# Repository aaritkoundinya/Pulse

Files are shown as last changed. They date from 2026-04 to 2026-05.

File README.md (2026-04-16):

# Pulse

Single-repo KiCad workspace for all Pulse board revisions.

## Repository Structure

- `boards/r2/` - imported from your existing `pulser2`
- `boards/r2.1/` - imported from your existing `pulser2.1`
- `templates/scratch-board/` - starter template for clean-slate revisions
- `tools/new_revision.sh` - helper script to create new revisions

Each board folder has its own KiCad-focused `.gitignore`.

## Create New Revisions

Build from an existing revision:

```bash
./tools/new_revision.sh r3 --from r2.1
```

Start from scratch:

```bash
./tools/new_revision.sh r3 --scratch
```

After creation, open KiCad and work in `boards/<revision>/`.

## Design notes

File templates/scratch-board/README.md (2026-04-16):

# Scratch KiCad Revision Template

Use this template when starting a brand-new board revision from zero.

Recommended first files to create in your new revision folder:
- `<revision>.kicad_pro`
- `<revision>.kicad_sch`
- `<revision>.kicad_pcb`

This folder already includes a KiCad-focused `.gitignore`.

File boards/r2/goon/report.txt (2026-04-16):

Info: Output directory 'C:\Users\roopa\Desktop\Basic Computer\airbrakes\goon' created.
Plotted to 'C:\Users\roopa\Desktop\Basic Computer\airbrakes\goon\airbrakes-F_Cu.gbr'.
Plotted to 'C:\Users\roopa\Desktop\Basic Computer\airbrakes\goon\airbrakes-B_Cu.gbr'.
Plotted to 'C:\Users\roopa\Desktop\Basic Computer\airbrakes\goon\airbrakes-F_Paste.gbr'.
Plotted to 'C:\Users\roopa\Desktop\Basic Computer\airbrakes\goon\airbrakes-B_Paste.gbr'.
Plotted to 'C:\Users\roopa\Desktop\Basic Computer\airbrakes\goon\airbrakes-F_Silkscreen.gbr'.
Plotted to 'C:\Users\roopa\Desktop\Basic Computer\airbrakes\goon\airbrakes-B_Silkscreen.gbr'.
Plotted to 'C:\Users\roopa\Desktop\Basic Computer\airbrakes\goon\airbrakes-F_Mask.gbr'.
Plotted to 'C:\Users\roopa\Desktop\Basic Computer\airbrakes\goon\airbrakes-B_Mask.gbr'.
Plotted to 'C:\Users\roopa\Desktop\Basic Computer\airbrakes\goon\airbrakes-Edge_Cuts.gbr'.
Created Gerber job file 'C:\Users\roopa\Desktop\Basic Computer\airbrakes\goon\airbrakes-job.gbrjob'.
Info: Done.
Plotted to 'C:\Users\roopa\Desktop\Basic Computer\airbrakes\goon\airbrakes-F_Cu.gbr'.
Plotted to 'C:\Users\roopa\Desktop\Basic Computer\airbrakes\goon\airbrakes-B_Cu.gbr'.
Plotted to 'C:\Users\roopa\Desktop\Basic Computer\airbrakes\goon\airbrakes-F_Paste.gbr'.
Plotted to 'C:\Users\roopa\Desktop\Basic Computer\airbrakes\goon\airbrakes-B_Paste.gbr'.
Plotted to 'C:\Users\roopa\Desktop\Basic Computer\airbrakes\goon\airbrakes-F_Silkscreen.gbr'.
Plotted to 'C:\Users\roopa\Desktop\Basic Computer\airbrakes\goon\airbrakes-B_Silkscreen.gbr'.
Plotted to 'C:\Users\roopa\Desktop\Basic Computer\airbrakes\goon\airbrakes-F_Mask.gbr'.
Plotted to 'C:\Users\roopa\Desktop\Basic Computer\airbrakes\goon\airbrakes-B_Mask.gbr'.
Plotted to 'C:\Users\roopa\Desktop\Basic Computer\airbrakes\goon\airbrakes-Edge_Cuts.gbr'.
Created Gerber job file 'C:\Users\roopa\Desktop\Basic Computer\airbrakes\goon\airbrakes-job.gbrjob'.
Info: Done.
Info: Done.
Info: Done.

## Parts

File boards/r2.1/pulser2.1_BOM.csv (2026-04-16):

Id | Designator | Footprint | Quantity | Designation | Supplier and ref
1 | U2 | SOT-23-5 | 1 | SPX3819M5-L-1-8
2 | C28 | C_0603_1608Metric | 1 | 10nF
3 | C25 | C_Elec_3x5.4 | 1 | 2.2uF
4 | R3,R4 | R_0603_1608Metric | 2 | 1k
5 | C16,C15 | C_0603_1608Metric | 2 | 15pF
6 | R6,R8,R9,R7 | R_0603_1608Metric | 4 | 4.7K
7 | U1 | QFN-56-1EP_7x7mm_P0.4mm_EP3.2x3.2mm | 1 | RP2040
8 | C22,C21,C23 | C_0603_1608Metric | 3 | 0.1uF
9 | PWR1,SW1 | PinHeader_1x02_P2.54mm_Vertical | 2 | Conn_01x02_Pin
10 | C20,C19 | C_0603_1608Metric | 2 | 100nf
11 | C26,C27 | C_0603_1608Metric | 2 | 22uF
12 | C17,C13,C14 | C_0603_1608Metric | 3 | 10uF
13 | BZ1 | MagneticBuzzer_CUI_CMT-8504-100-SMT | 1 | Buzzer
14 | U3 | SOT23-5 | 1 | AP2112K-3.3
15 | C24,C1,C4 | C_0603_1608Metric | 3 | 1uF
16 | R5,R11 | R_0603_1608Metric | 2 | 10K
17 | USB1 | USB_Micro-B_Wuerth_629105150521 | 1 | USB_B_Micro
18 | IMU1 | InvenSense_QFN-24_3x3mm_P0.4mm | 1 | ICM-20948
19 | CLOCK1 | XTAL_ABM8-272-T3 | 1 | ABM8-272-T3
20 | C18,C12,C9,C7,C10,C6,C8,C3,C11,C2,C5 | C_0603_1608Metric | 11 | 100nF
21 | D2,D5 | D_0603_1608Metric | 2 | D_Schottky
22 | L1 | L_0603_1608Metric | 1 | 2.2uH
23 | G1 | LED_0603_1608Metric | 1 | GREEN
24 | BMP1 | BMP581 | 1 | BMP581
25 | R12 | LED_0603_1608Metric | 1 | RED
26 | SERVO1 | PinHeader_1x03_P2.54mm_Horizontal | 1 | Conn_01x03_Pin
27 | U6 | SOT-563 | 1 | AP62250Z6
28 | BOOTSL1,RST1 | Push_SMD_4.2x3.2mm | 2 | SMD_4.2x3.2mm_h2.5mm
29 | R1,R2 | R_0603_1608Metric | 2 | 27.4
30 | FLASH1 | SOIC-8_5.3x5.3mm_P1.27mm | 1 | W25Q128JVS
31 | RADIO1,GPIO1 | JST_PH_B4B-PH-K_1x04_P2.00mm_Vertical | 2 | Conn_01x04_Socket
32 | R10 | R_0603_1608Metric | 1 | 52.3K
33 | D1 | LED_0603_1608Metric | 1 | LED

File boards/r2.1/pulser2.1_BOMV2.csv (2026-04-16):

Id | Designator | Footprint | Quantity | Designation | Supplier and ref
1 | R3,R4 | R_0603_1608Metric | 2 | 1k
2 | C21,C18,C12,C23,C9,C7,C10,C6,C8,C3,C11,C2,C5 | C_0603_1608Metric | 13 | 100nF
3 | C16,C15 | C_0603_1608Metric | 2 | 15pF
4 | U1 | QFN-56-1EP_7x7mm_P0.4mm_EP3.2x3.2mm | 1 | RP2040
5 | PWR,SW1 | PinHeader_1x02_P2.54mm_Vertical | 2 | Conn_01x02_Pin
6 | C20,C19 | C_0603_1608Metric | 2 | 100nf
7 | C26,C27 | C_0603_1608Metric | 2 | 22uF
8 | C17,C13,C14 | C_0603_1608Metric | 3 | 10uF
9 | BZ | Buzzer_CUI_CPT-9019S-SMT | 1 | Buzzer
10 | U3 | SOT23-5 | 1 | AP2112K-3.3
11 | U5 | ST_LGA-14L_2.5x3.0mm_P0.5mm_4x3 | 1 | LSM6DSOX
12 | R5,R11 | R_0603_1608Metric | 2 | 10K
13 | USB | USB_Micro-B_Wuerth_629105150521 | 1 | USB_B_Micro
14 | CLOCK1 | XTAL_ABM8-272-T3 | 1 | ABM8-272-T3
15 | C1,C4 | C_0603_1608Metric | 2 | 1uF
16 | D2,D5 | D_SOD-323_HandSoldering | 2 | D_Schottky
17 | L1 | L_0603_1608Metric | 1 | 2.2uH
18 | G1 | LED_0603_1608Metric | 1 | GREEN
19 | BMP | BMP581 | 1 | BMP581
20 | R13,R14 | R_0402_1005Metric | 2 | 680
21 | R12 | LED_0603_1608Metric | 1 | RED
22 | SERVO | PinHeader_1x03_P2.54mm_Horizontal | 1 | Conn_01x03_Pin
23 | R6,R7 | R_0603_1608Metric | 2 | 4.7K
24 | U6 | SOT-563 | 1 | AP62250Z6
25 | BOOTSL,RST | Push_SMD_4.2x3.2mm | 2 | SMD_4.2x3.2mm_h2.5mm
26 | R1,R2 | R_0603_1608Metric | 2 | 27.4
27 | FLASH | WSON-8-1EP_6x5mm_P1.27mm_EP3.4x4.3mm | 1 | W25Q128JVS
28 | RADIO1,GPIO | JST_PH_B4B-PH-K_1x04_P2.00mm_Vertical | 2 | Conn_01x04_Socket
29 | R10 | R_0603_1608Metric | 1 | 52.3K
30 | D1 | LED_0603_1608Metric | 1 | LED
31 | R15 | R_0402_1005Metric | 1 | 1k

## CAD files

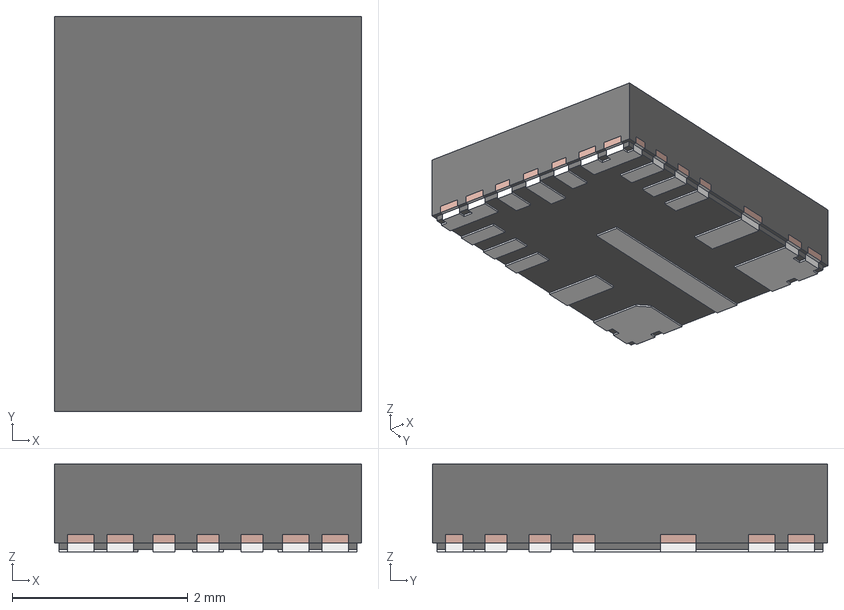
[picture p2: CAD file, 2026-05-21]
boards/r3/LM62460Q5RPHRQ1/RPH0016A.stp
3.50 x 4.50 x 1.00 mm
FRAME_AF0
BODY_AF0
PIN1_AREA

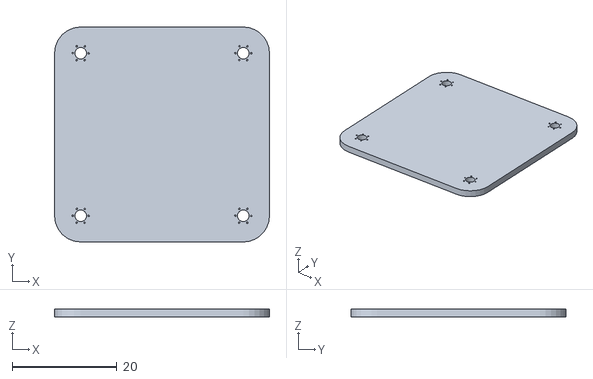
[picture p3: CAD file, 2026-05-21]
boards/r3/pulser3.stl
41.0 x 41.0 x 1.51

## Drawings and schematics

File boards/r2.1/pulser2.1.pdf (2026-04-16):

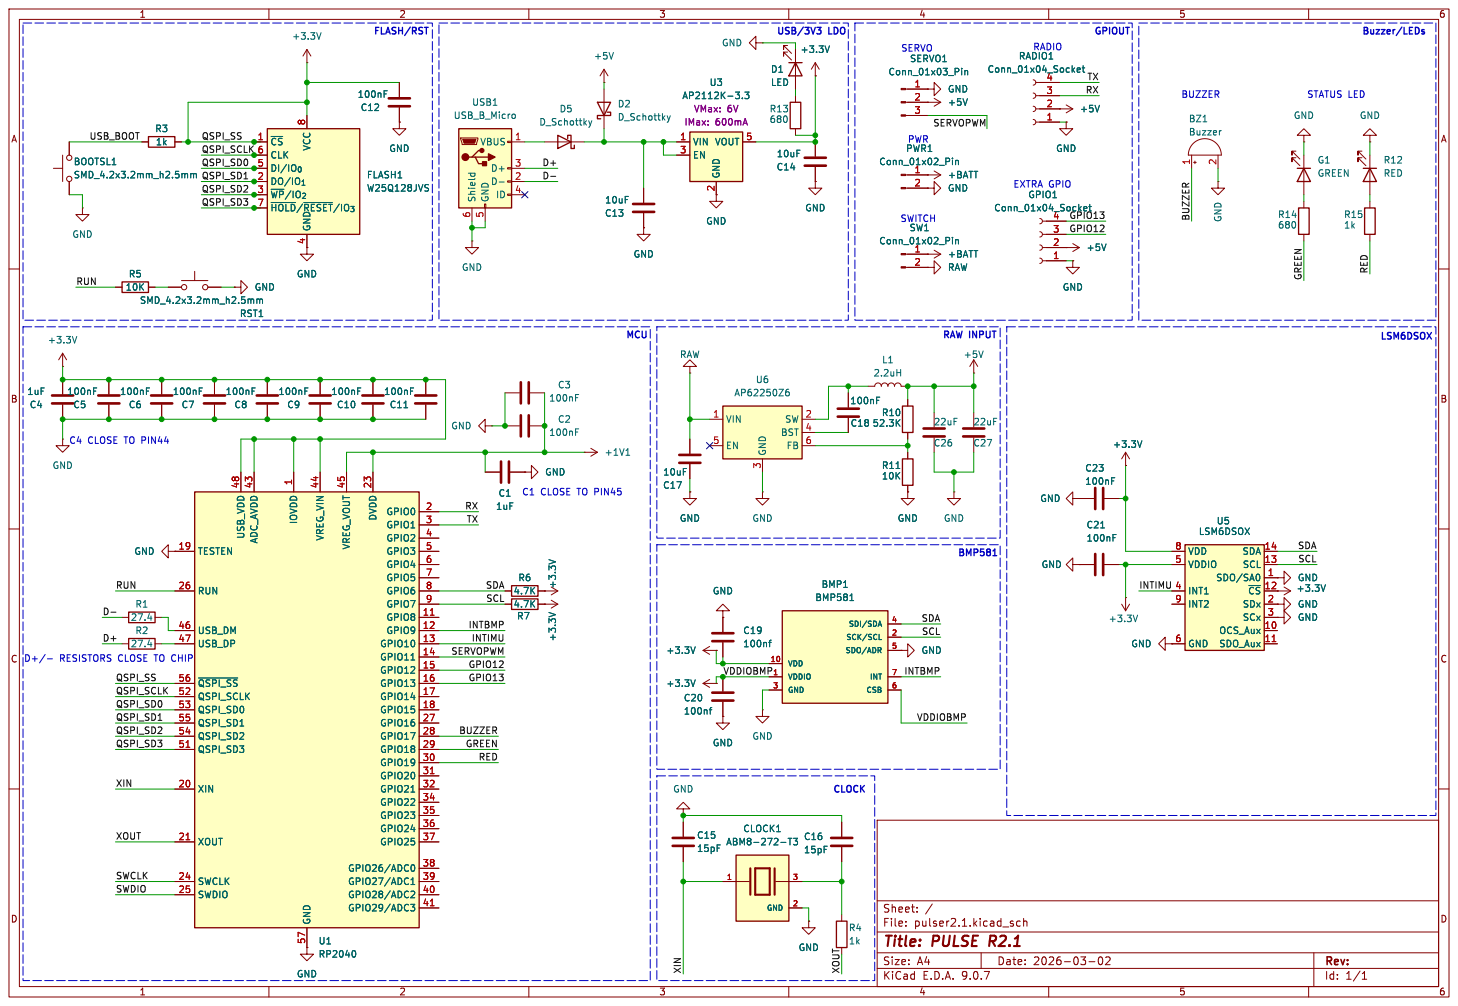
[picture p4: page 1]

File: pulser2.1.kicad_sch Sheet: / GND GND

3 SW 2 BST 4 FB 6 U6 AP62250Z6 GND

LSM6DSOX
SDA 14 SCL 13 ~{CS} 12 OCS_Aux 10 SDO_Aux 11 VDD 8 VDDIO 5

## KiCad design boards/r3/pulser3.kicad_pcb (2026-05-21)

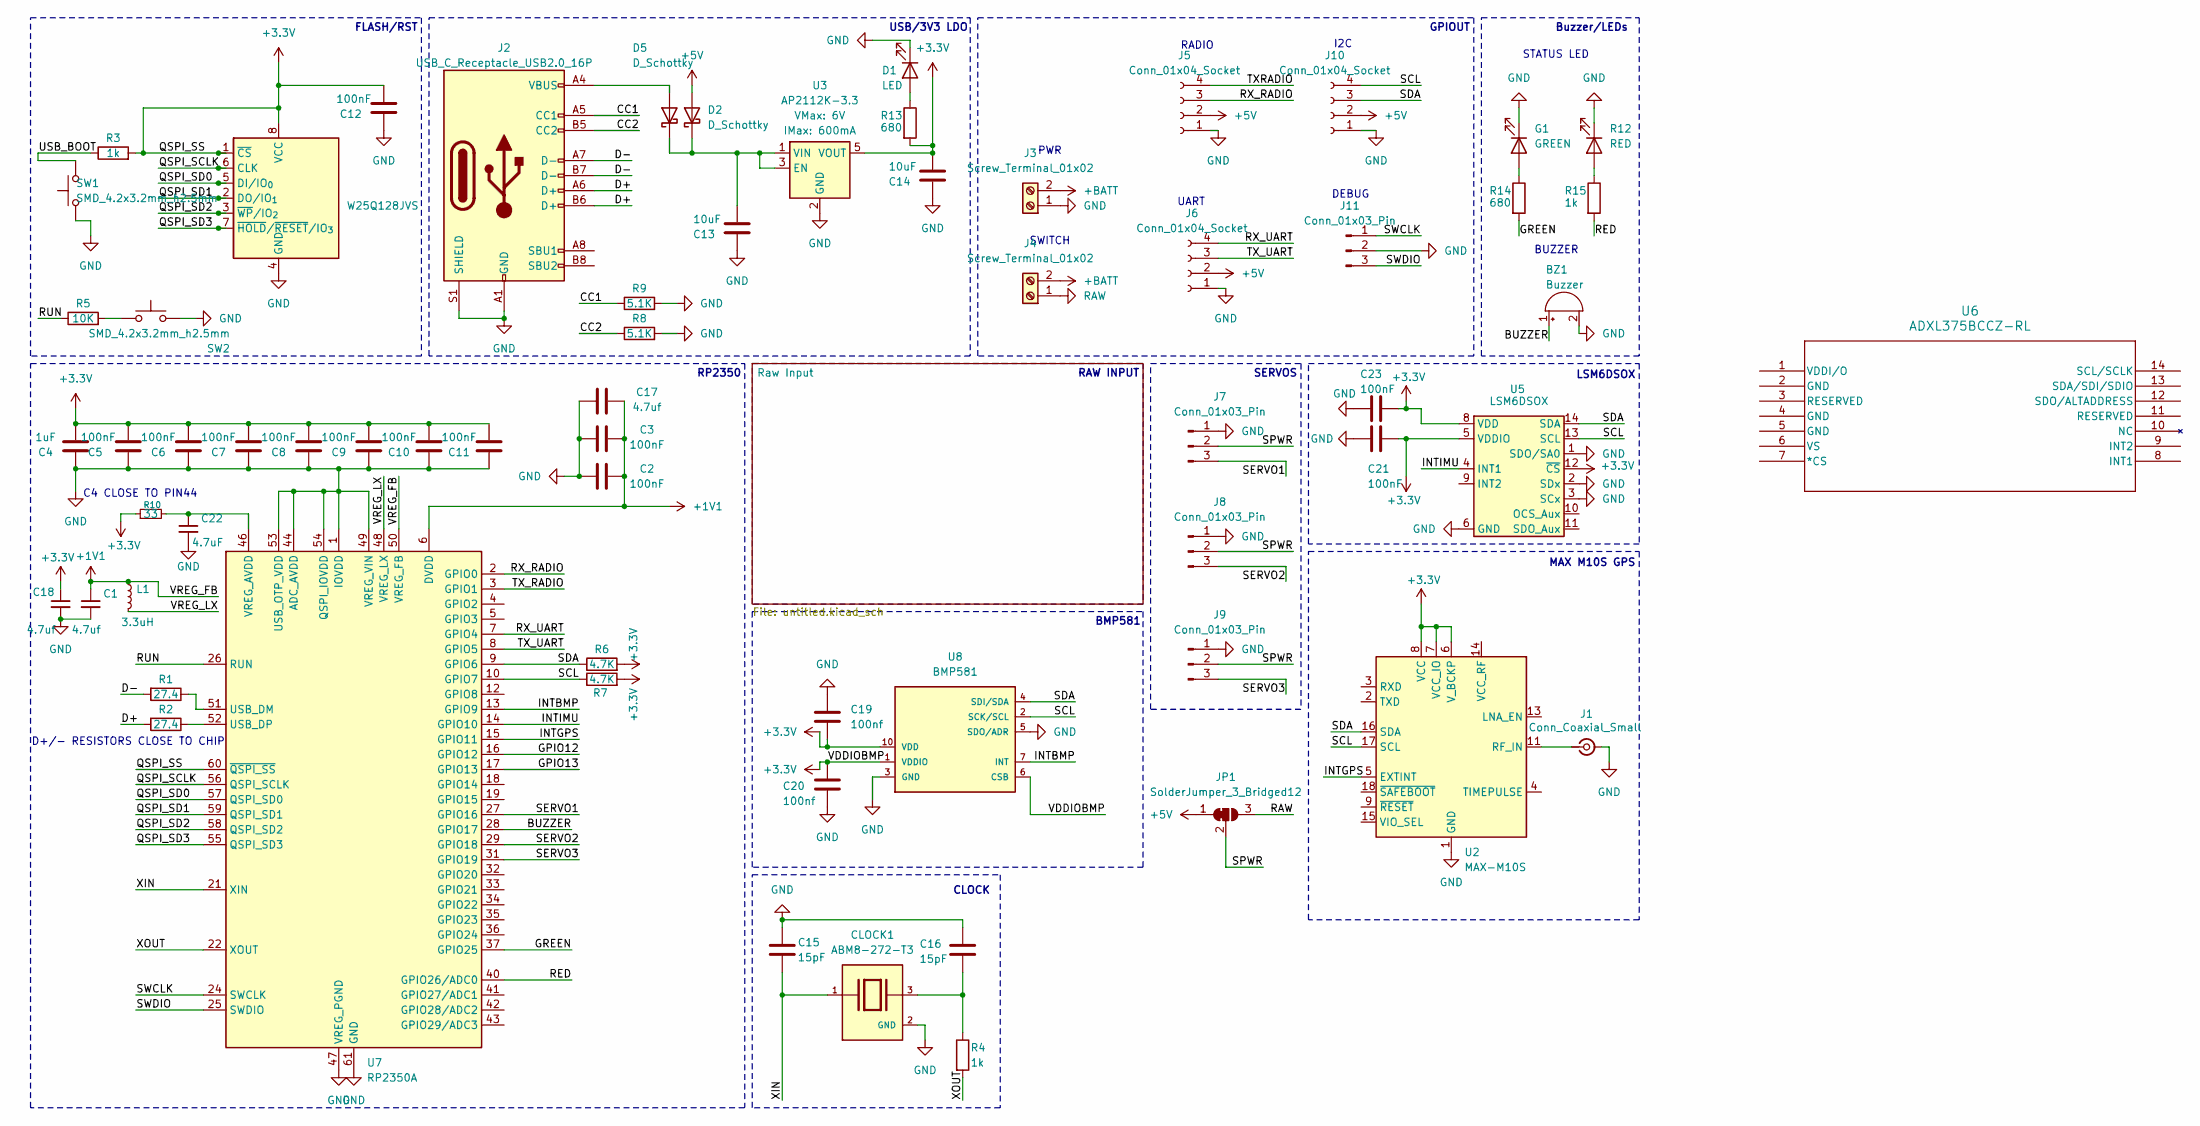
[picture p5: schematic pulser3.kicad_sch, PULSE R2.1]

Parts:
BZ1: Buzzer; Buzzer_CUI_CPT-9019S-SMT
C1, C17, C18: 4.7uf; C_0402_1005Metric
C2, C3, C5, C6, C7, C8, C9, C10, C11, C12, C21, C23: 100nF; C_0402_1005Metric
C4: 1uF; C_0402_1005Metric
C13, C14: 10uF; C_0805_2012Metric
C15, C16: 15pF; C_0402_1005Metric
C19, C20: 100nf; C_0402_1005Metric
C22: 4.7uF; C_0402_1005Metric
CLOCK1: ABM8-272-T3; XTAL_ABM8-272-T3; PARTREV 07-29-20
D1: LED; LED_0603_1608Metric
D2, D5: D_Schottky; D_SOD-323_HandSoldering
G1: GREEN; LED_0603_1608Metric
J1: Conn_Coaxial_Small; U.FL_Molex_MCRF_73412-0110_Vertical
J2: USB_C_Receptacle_USB2.0_16P; USB_C_Receptacle_JAE_DX07S016JA1R1500
J3, J4: Screw_Terminal_01x02; TerminalBlock_Phoenix_MPT-0,5-2-2.54_1x02_P2.54mm_Horizontal
J5, J6, J10: Conn_01x04_Socket; JST_SH_BM04B-SRSS-TB_1x04-1MP_P1.00mm_Vertical
J7, J8, J9, J11: Conn_01x03_Pin; JST_SH_BM03B-SRSS-TB_1x03-1MP_P1.00mm_Vertical
JP1: SolderJumper_3_Bridged12; SolderJumper-3_P1.3mm_Open_RoundedPad1.0x1.5mm
L1: 3.3uH; Untitled
R1, R2: 27.4; R_0402_1005Metric
R3, R4, R15: 1k; R_0402_1005Metric
R5: 10K; R_0402_1005Metric
R6, R7: 4.7K; R_0402_1005Metric
R8, R9: 5.1K; R_0402_1005Metric
R10: 33; R_0402_1005Metric
R12: RED; LED_0603_1608Metric
R13, R14: 680; R_0402_1005Metric
SW1, SW2: SMD_4.2x3.2mm_h2.5mm; Push_SMD_4.2x3.2mm
U1: W25Q128JVS; WSON-8-1EP_6x5mm_P1.27mm_EP3.4x4.3mm
U2: MAX-M10S; ublox_MAX
U3: AP2112K-3.3; SOT23-5
U5: LSM6DSOX; ST_LGA-14L_2.5x3.0mm_P0.5mm_4x3
U6: ADXL375BCCZ-RL
U7: RP2350A; QFN-60-1EP_7x7mm_P0.4mm_EP3.4x3.4mm
U8: BMP581

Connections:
+1V1: C1.1, C2.2, C3.2, C17.2, L1.1, U7.6 (DVDD), U7.23 (DVDD), U7.39 (DVDD), U7.50 (VREG_FB)
+3.3V: C4.1, C5.1, C6.1, C7.1, C8.1, C9.1, C10.1, C11.1, C12.1, C14.1, C18.1, C19.2, C20.1, C21.2, C23.2, R3.2, R6.2, R7.2, R10.1, R13.2, U1.1 (~CS), U1.8 (VCC), U2.6 (V_BCKP), U2.7 (VCC_IO), U2.8 (VCC), U3.5 (VOUT), U5.5 (VDDIO), U5.8 (VDD), U5.12 (~CS), U7.60 (~QSPI_SS), U8.1 (VDDIO), U8.6 (CSB), U8.10 (VDD)
+5V: D2.2 (A), J5.2, J6.2, J10.2, JP1.1 (A)
+BATT: J3.2, J4.2
/BUZZER: BZ1.1 (+), U7.28 (GPIO17)
/CC1: J2.A5 (CC1), R9.1
/CC2: J2.B5 (CC2), R8.1
/D+: J2.A6 (D+), J2.B6 (D+), R2.2
/D-: J2.A7 (D-), J2.B7 (D-), R1.2
/GPIO12: U7.16 (GPIO12)
/GPIO13: U7.17 (GPIO13)
/GREEN: R14.2, U7.37 (GPIO25)
/INTBMP: U7.13 (GPIO9), U8.7 (INT)
/INTGPS: U2.5 (EXTINT), U7.15 (GPIO11)
/INTIMU: U5.4 (INT1), U7.14 (GPIO10)
/QSPI_SCLK: U1.6 (CLK), U7.56 (QSPI_SCLK)
/QSPI_SD0: U1.5 (DI/IO_{0}), U7.57 (QSPI_SD0)
/QSPI_SD1: U1.2 (DO/IO_{1}), U7.59 (QSPI_SD1)
/QSPI_SD2: U1.3 (~WP/IO_{2}), U7.58 (QSPI_SD2)
/QSPI_SD3: U1.7 (~HOLD/~RESET/IO_{3}), U7.55 (QSPI_SD3)
/RED: R15.2, U7.40 (GPIO26/ADC0)
/RUN: R5.1, U7.26 (RUN)
/RX_RADIO: J5.3, U7.2 (GPIO0)
/RX_UART: J6.4, U7.7 (GPIO4)
/SCL: J10.4, R7.1, U2.17 (SCL), U5.13 (SCL), U7.10 (GPIO7), U8.2 (SCK/SCL)
/SDA: J10.3, R6.1, U2.16 (SDA), U5.14 (SDA), U7.9 (GPIO6), U8.4 (SDI/SDA)
/SERVO1: J7.3, U7.27 (GPIO16)
/SERVO2: J8.3, U7.29 (GPIO18)
/SERVO3: J9.3, U7.31 (GPIO19)
/SPWR: J7.2, J8.2, J9.2, JP1.2 (C)
/SWCLK: J11.1, U7.24 (SWCLK)
/SWDIO: J11.3, U7.25 (SWDIO)
/TXRADIO: J5.4
/TX_RADIO: U7.3 (GPIO1)
/TX_UART: J6.3, U7.8 (GPIO5)
/USB_BOOT: R3.1, SW1.2
/VREG_LX: L1.2, U7.48 (VREG_LX)
/XIN: C15.2, CLOCK1.1, U7.21 (XIN)
/XOUT: R4.2, U7.22 (XOUT)
GND: BZ1.2 (-), C1.2, C2.1, C3.1, C4.2, C5.2, C6.2, C7.2, C8.2, C9.2, C10.2, C11.2, C12.2, C13.2, C14.2, C15.1, C16.1, C17.1, C18.2, C19.1, C20.2, C21.1, C22.2, C23.1, CLOCK1.2 (GND), CLOCK1.4 (GND), D1.1 (K), G1.1 (K), J1.2 (Ext), J2.A1 (GND), J2.A12 (GND), J2.B1 (GND), J2.B12 (GND), J2.S1 (SHIELD), J3.1, J5.1, J6.1, J7.1, J8.1, J9.1, J10.1, J11.2, R8.2, R9.2, R12.1 (K), SW1.1, SW2.2, U1.4 (GND), U2.1 (GND), U2.10 (GND), U2.12 (GND), U3.2 (GND), U5.1 (SDO/SA0), U5.2 (SDx), U5.3 (SCx), U5.6 (GND), U5.7 (GND), U7.1 (IOVDD), U7.11 (IOVDD), U7.20 (IOVDD), U7.30 (IOVDD), U7.38 (IOVDD), U7.44 (ADC_AVDD), U7.45 (IOVDD), U7.47 (VREG_PGND), U7.49 (VREG_VIN), U7.53 (USB_OTP_VDD), U7.54 (QSPI_IOVDD), U7.61 (GND), U8.3 (GND), U8.5 (SDO/ADR), U8.8 (GND), U8.9 (GND)
unnamed: C16.2, CLOCK1.3, R4.1
unnamed: D1.2 (A), R13.1
unnamed: C13.1, D2.1 (K), D5.1 (K), U3.1 (VIN), U3.3 (EN)
unnamed: D5.2 (A), J2.A4 (VBUS), J2.A9 (VBUS), J2.B4 (VBUS), J2.B9 (VBUS)
unnamed: G1.2 (A), R14.1
unnamed: J1.1 (In), U2.11 (RF_IN)
unnamed: R5.2, SW2.1
unnamed: R12.2 (A), R15.1
unnamed: R1.1, U7.51 (USB_DM)
unnamed: R2.1, U7.52 (USB_DP)
unnamed: C22.1, R10.2, U7.46 (VREG_AVDD)
RAW: J4.1, JP1.3 (B)

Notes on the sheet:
MAX M10S GPS
PWR
FLASH/RST
RP2350
USB/3V3 LDO
RAW INPUT
D+/- RESISTORS CLOSE TO CHIP
RADIO
C4 CLOSE TO PIN44
BUZZER
SERVOS
I2C
STATUS LED
SWITCH
BMP581
DEBUG
CLOCK
UART
LSM6DSOX
Buzzer/LEDs
GPIOUT

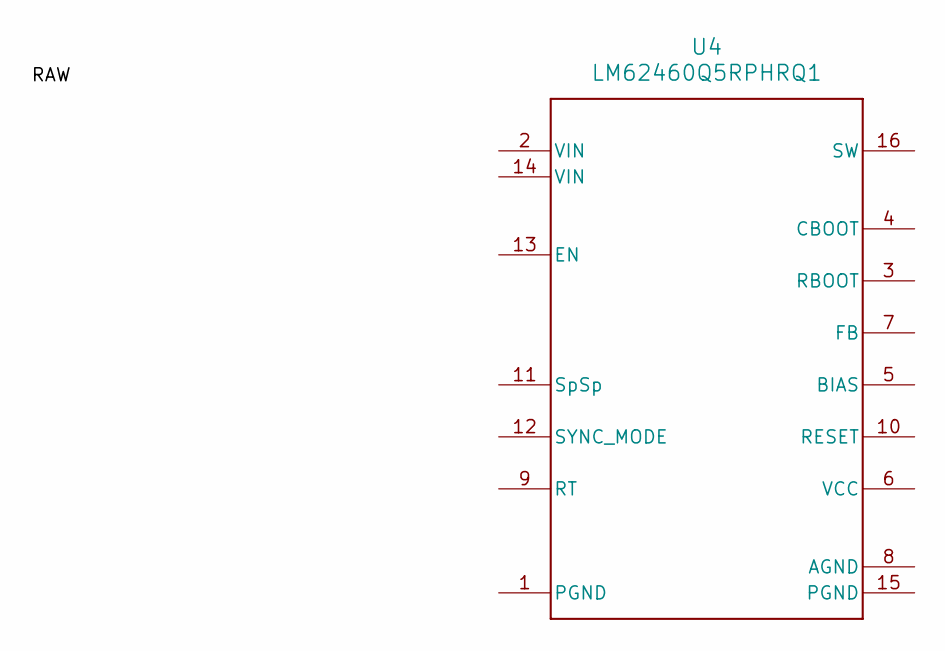
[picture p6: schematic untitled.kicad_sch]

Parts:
U4: LM62460Q5RPHRQ1

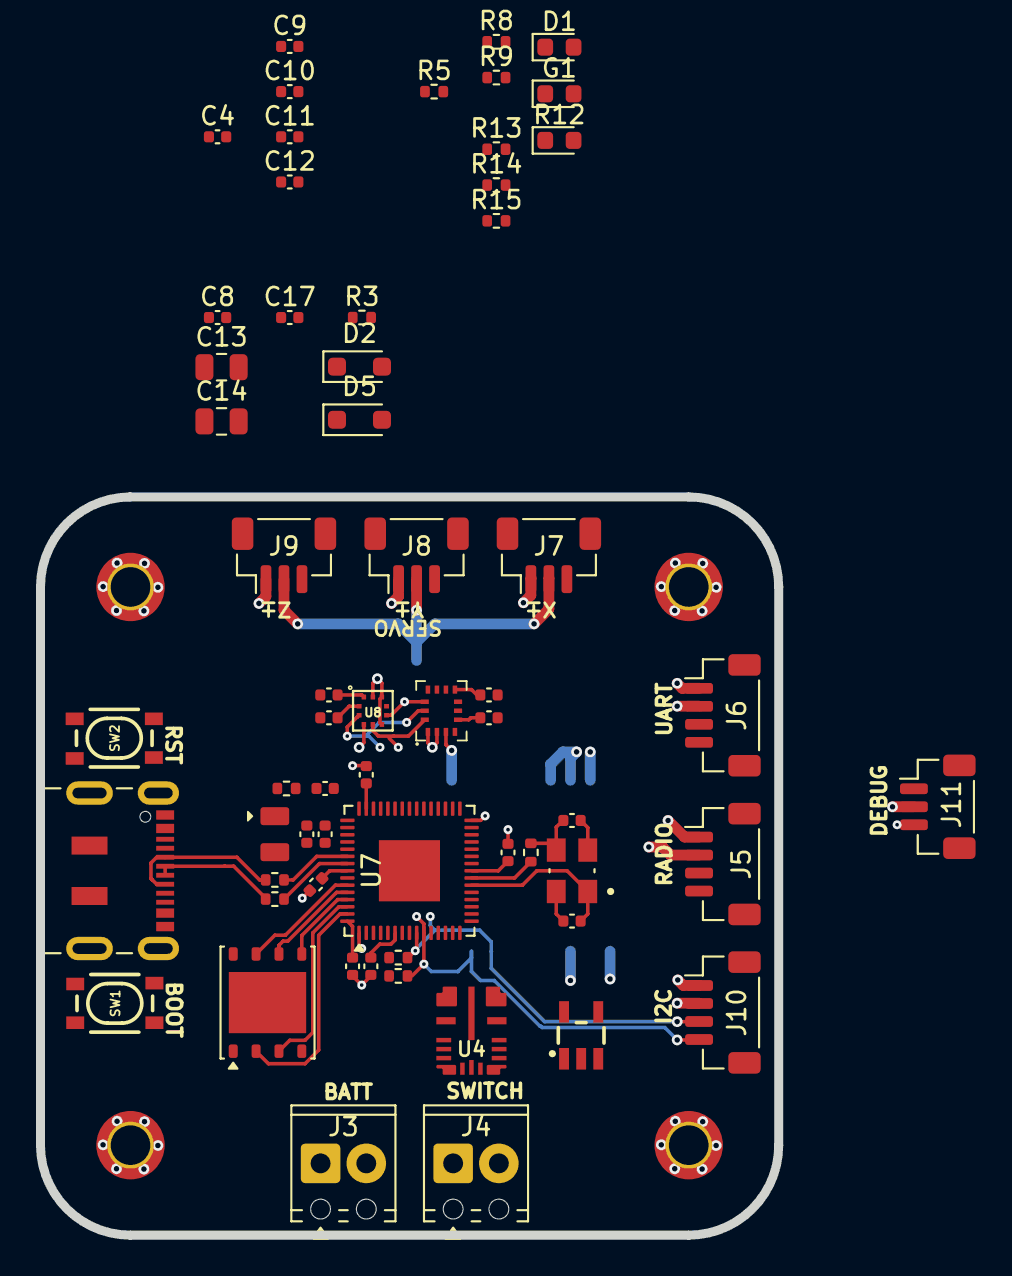
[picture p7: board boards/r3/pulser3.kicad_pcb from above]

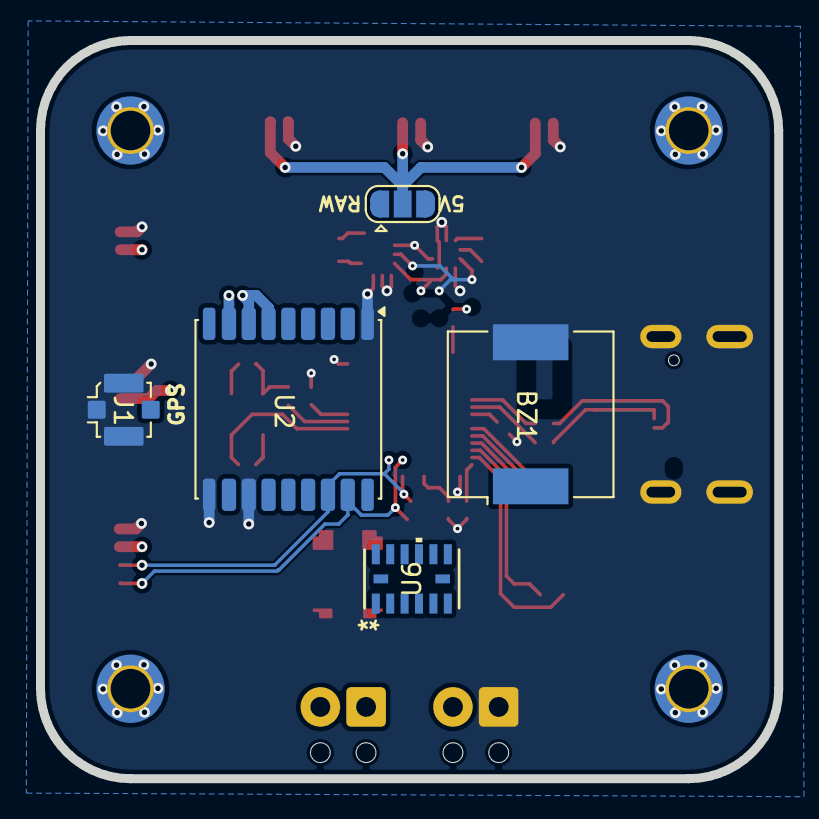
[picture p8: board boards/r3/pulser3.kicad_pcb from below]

Board: 4 copper layers, 41.0 x 41.0 mm, 66 parts (5 on the bottom side), 48 nets.

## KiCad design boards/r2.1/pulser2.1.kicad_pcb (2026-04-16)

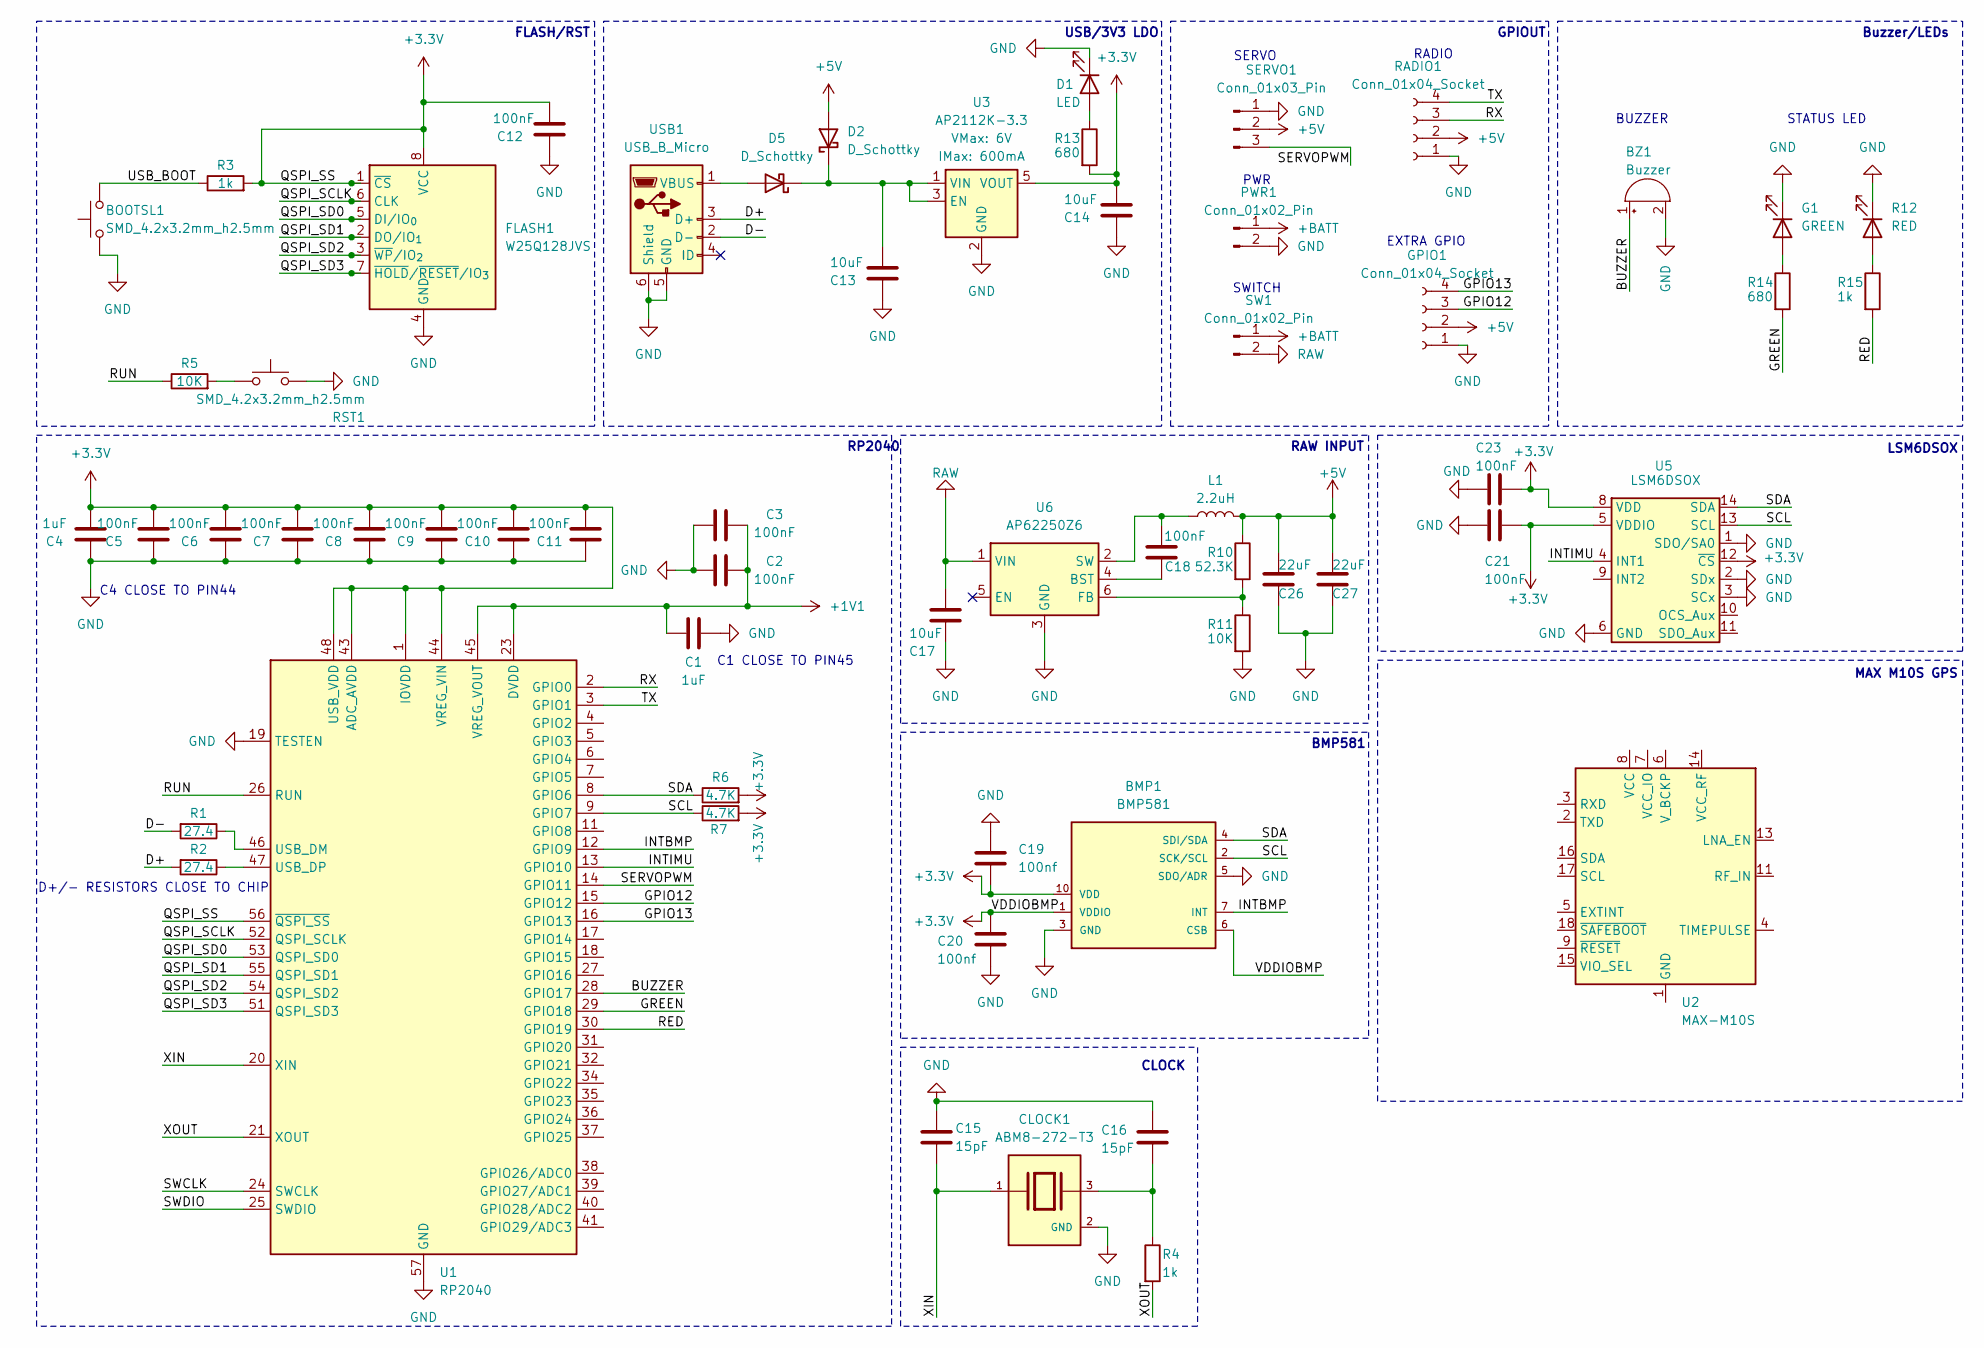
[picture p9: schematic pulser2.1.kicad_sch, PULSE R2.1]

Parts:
BMP1: BMP581
BOOTSL1: SMD_4.2x3.2mm_h2.5mm; Push_SMD_4.2x3.2mm
BZ1: Buzzer; Buzzer_CUI_CPT-9019S-SMT
C1, C4: 1uF; C_0603_1608Metric
C2, C3, C5, C6, C7, C8, C9, C10, C11, C12, C18, C21, C23: 100nF; C_0603_1608Metric
C13, C14, C17: 10uF; C_0805_2012Metric
C15, C16: 15pF; C_0603_1608Metric
C19, C20: 100nf; C_0603_1608Metric
C26, C27: 22uF; C_1206_3216Metric
CLOCK1: ABM8-272-T3; XTAL_ABM8-272-T3; PARTREV 07-29-20
D1: LED; LED_0603_1608Metric
D2, D5: D_Schottky; D_SOD-323_HandSoldering
FLASH1: W25Q128JVS; WSON-8-1EP_6x5mm_P1.27mm_EP3.4x4.3mm
G1: GREEN; LED_0603_1608Metric
GPIO1: Conn_01x04_Socket; JST_PH_B4B-PH-K_1x04_P2.00mm_Vertical
L1: 2.2uH; L_Vishay_IHLP-1616
PWR1: Conn_01x02_Pin; PinHeader_1x02_P2.54mm_Vertical
R1, R2: 27.4; R_0603_1608Metric
R3, R4: 1k; R_0603_1608Metric
R5, R11: 10K; R_0603_1608Metric
R6, R7: 4.7K; R_0603_1608Metric
R10: 52.3K; R_0603_1608Metric
R12: RED; LED_0603_1608Metric
R13, R14: 680; R_0402_1005Metric
R15: 1k; R_0402_1005Metric
RADIO1: Conn_01x04_Socket; JST_PH_B4B-PH-K_1x04_P2.00mm_Vertical
RST1: SMD_4.2x3.2mm_h2.5mm; Push_SMD_4.2x3.2mm
SERVO1: Conn_01x03_Pin; PinHeader_1x03_P2.54mm_Horizontal
SW1: Conn_01x02_Pin; PinHeader_1x02_P2.54mm_Vertical
U1: RP2040; QFN-56-1EP_7x7mm_P0.4mm_EP3.2x3.2mm
U2: MAX-M10S; ublox_MAX
U3: AP2112K-3.3; SOT23-5
U5: LSM6DSOX; ST_LGA-14L_2.5x3.0mm_P0.5mm_4x3
U6: AP62250Z6; SOT-563
USB1: USB_B_Micro; USB_Micro-B_Wuerth_629105150521

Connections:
+1V1: C1.1, C2.2, C3.2, U1.23 (DVDD), U1.45 (VREG_VOUT), U1.50 (DVDD)
+3.3V: BMP1.1 (VDDIO), BMP1.6 (CSB), BMP1.10 (VDD), C4.1, C5.1, C6.1, C7.1, C8.1, C9.1, C10.1, C11.1, C12.1, C14.1, C19.2, C20.1, C21.2, C23.2, FLASH1.1 (~CS), FLASH1.8 (VCC), R3.2, R6.2, R7.2, R13.2, U1.1 (IOVDD), U1.10 (IOVDD), U1.22 (IOVDD), U1.33 (IOVDD), U1.42 (IOVDD), U1.43 (ADC_AVDD), U1.44 (VREG_VIN), U1.48 (USB_VDD), U1.49 (IOVDD), U1.56 (~QSPI_SS), U3.5 (VOUT), U5.5 (VDDIO), U5.8 (VDD), U5.12 (~CS)
+5V: C26.1, C27.1, D2.2 (A), GPIO1.2, L1.2, R10.1, RADIO1.2, SERVO1.2
+BATT: PWR1.1, SW1.1
/BUZZER: BZ1.1 (+), U1.28 (GPIO17)
/D+: R2.2, USB1.3 (D+)
/D-: R1.2, USB1.2 (D-)
/GPIO12: GPIO1.3, U1.15 (GPIO12)
/GPIO13: GPIO1.4, U1.16 (GPIO13)
/GREEN: R14.2, U1.29 (GPIO18)
/INTBMP: BMP1.7 (INT), U1.12 (GPIO9)
/INTIMU: U1.13 (GPIO10), U5.4 (INT1)
/QSPI_SCLK: FLASH1.6 (CLK), U1.52 (QSPI_SCLK)
/QSPI_SD0: FLASH1.5 (DI/IO_{0}), U1.53 (QSPI_SD0)
/QSPI_SD1: FLASH1.2 (DO/IO_{1}), U1.55 (QSPI_SD1)
/QSPI_SD2: FLASH1.3 (~WP/IO_{2}), U1.54 (QSPI_SD2)
/QSPI_SD3: FLASH1.7 (~HOLD/~RESET/IO_{3}), U1.51 (QSPI_SD3)
/RED: R15.2, U1.30 (GPIO19)
/RUN: R5.1, U1.26 (RUN)
/RX: RADIO1.3, U1.2 (GPIO0)
/SCL: BMP1.2 (SCK/SCL), R7.1, U1.9 (GPIO7), U5.13 (SCL)
/SDA: BMP1.4 (SDI/SDA), R6.1, U1.8 (GPIO6), U5.14 (SDA)
/SERVOPWM: SERVO1.3, U1.14 (GPIO11)
/SWCLK: U1.24 (SWCLK)
/SWDIO: U1.25 (SWDIO)
/TX: RADIO1.4, U1.3 (GPIO1)
/USB_BOOT: BOOTSL1.2, R3.1
/XIN: C15.2, CLOCK1.1, U1.20 (XIN)
/XOUT: R4.2, U1.21 (XOUT)
GND: BMP1.3 (GND), BMP1.5 (SDO/ADR), BMP1.8 (GND), BMP1.9 (GND), BOOTSL1.1, BZ1.2 (-), C1.2, C2.1, C3.1, C4.2, C5.2, C6.2, C7.2, C8.2, C9.2, C10.2, C11.2, C12.2, C13.2, C14.2, C15.1, C16.1, C17.2, C19.1, C20.2, C21.1, C23.1, C26.2, C27.2, CLOCK1.2 (GND), CLOCK1.4 (GND), D1.1 (K), FLASH1.4 (GND), G1.1 (K), GPIO1.1, PWR1.2, R11.2, R12.1 (K), RADIO1.1, RST1.2, SERVO1.1, U1.19 (TESTEN), U1.57 (GND), U3.2 (GND), U5.1 (SDO/SA0), U5.2 (SDx), U5.3 (SCx), U5.6 (GND), U5.7 (GND), U6.3 (GND), USB1.5 (GND), USB1.6 (Shield)
unnamed: C16.2, CLOCK1.3, R4.1
unnamed: D1.2 (A), R13.1
unnamed: C13.1, D2.1 (K), D5.1 (K), U3.1 (VIN), U3.3 (EN)
unnamed: D5.2 (A), USB1.1 (VBUS)
unnamed: G1.2 (A), R14.1
unnamed: R5.2, RST1.1
unnamed: R12.2 (A), R15.1
unnamed: R1.1, U1.46 (USB_DM)
unnamed: R2.1, U1.47 (USB_DP)
unnamed: U2.1 (GND), U2.10 (GND), U2.12 (GND)
unnamed: C18.2, U6.4 (BST)
unnamed: R10.2, R11.1, U6.6 (FB)
unnamed: C18.1, L1.1, U6.2 (SW)
RAW: C17.1, SW1.2, U6.1 (VIN)

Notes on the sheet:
MAX M10S GPS
PWR
FLASH/RST
RP2040
USB/3V3 LDO
RAW INPUT
D+/- RESISTORS CLOSE TO CHIP
RADIO
SERVO
C4 CLOSE TO PIN44
BUZZER
C1 CLOSE TO PIN45
STATUS LED
SWITCH
BMP581
CLOCK
EXTRA GPIO
LSM6DSOX
Buzzer/LEDs
GPIOUT

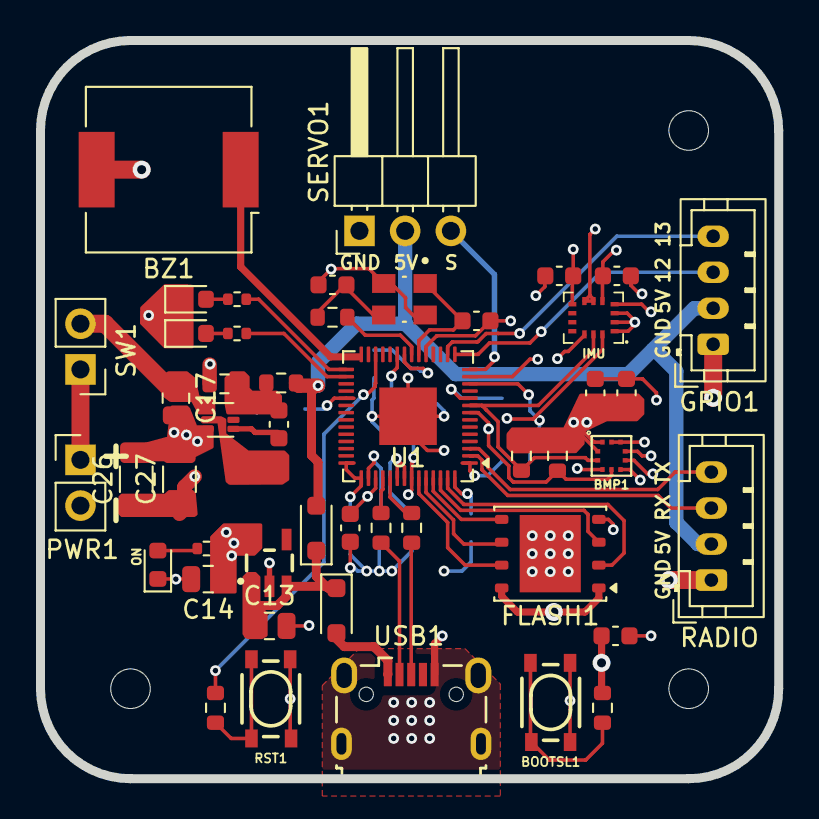
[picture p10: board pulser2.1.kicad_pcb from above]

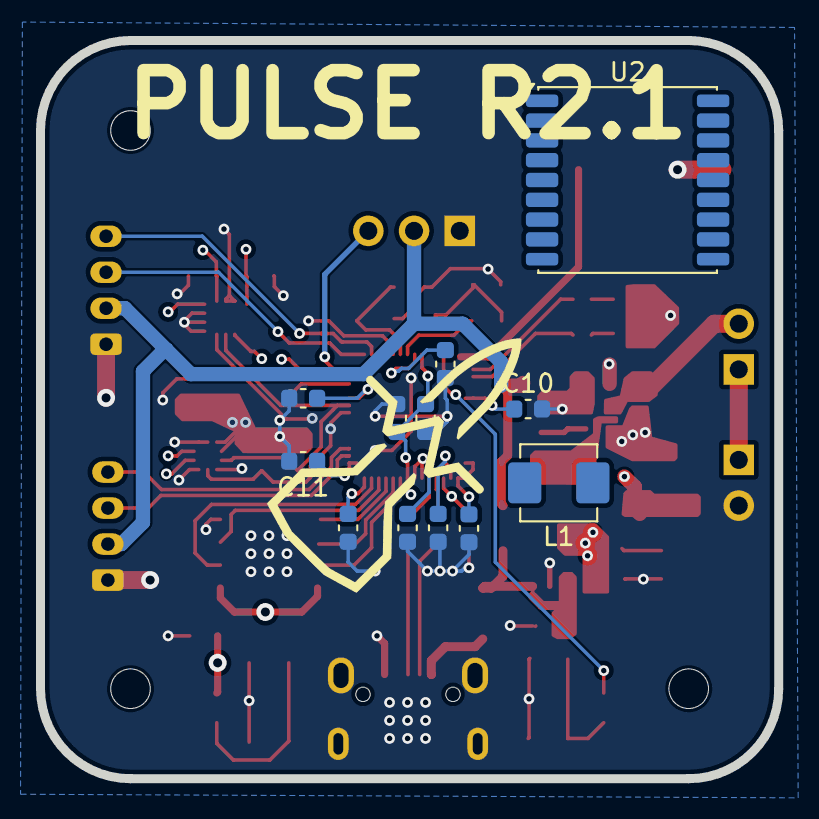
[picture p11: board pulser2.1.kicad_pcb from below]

Board: 4 copper layers, 41.0 x 41.0 mm, 59 parts (12 on the bottom side), 42 nets.

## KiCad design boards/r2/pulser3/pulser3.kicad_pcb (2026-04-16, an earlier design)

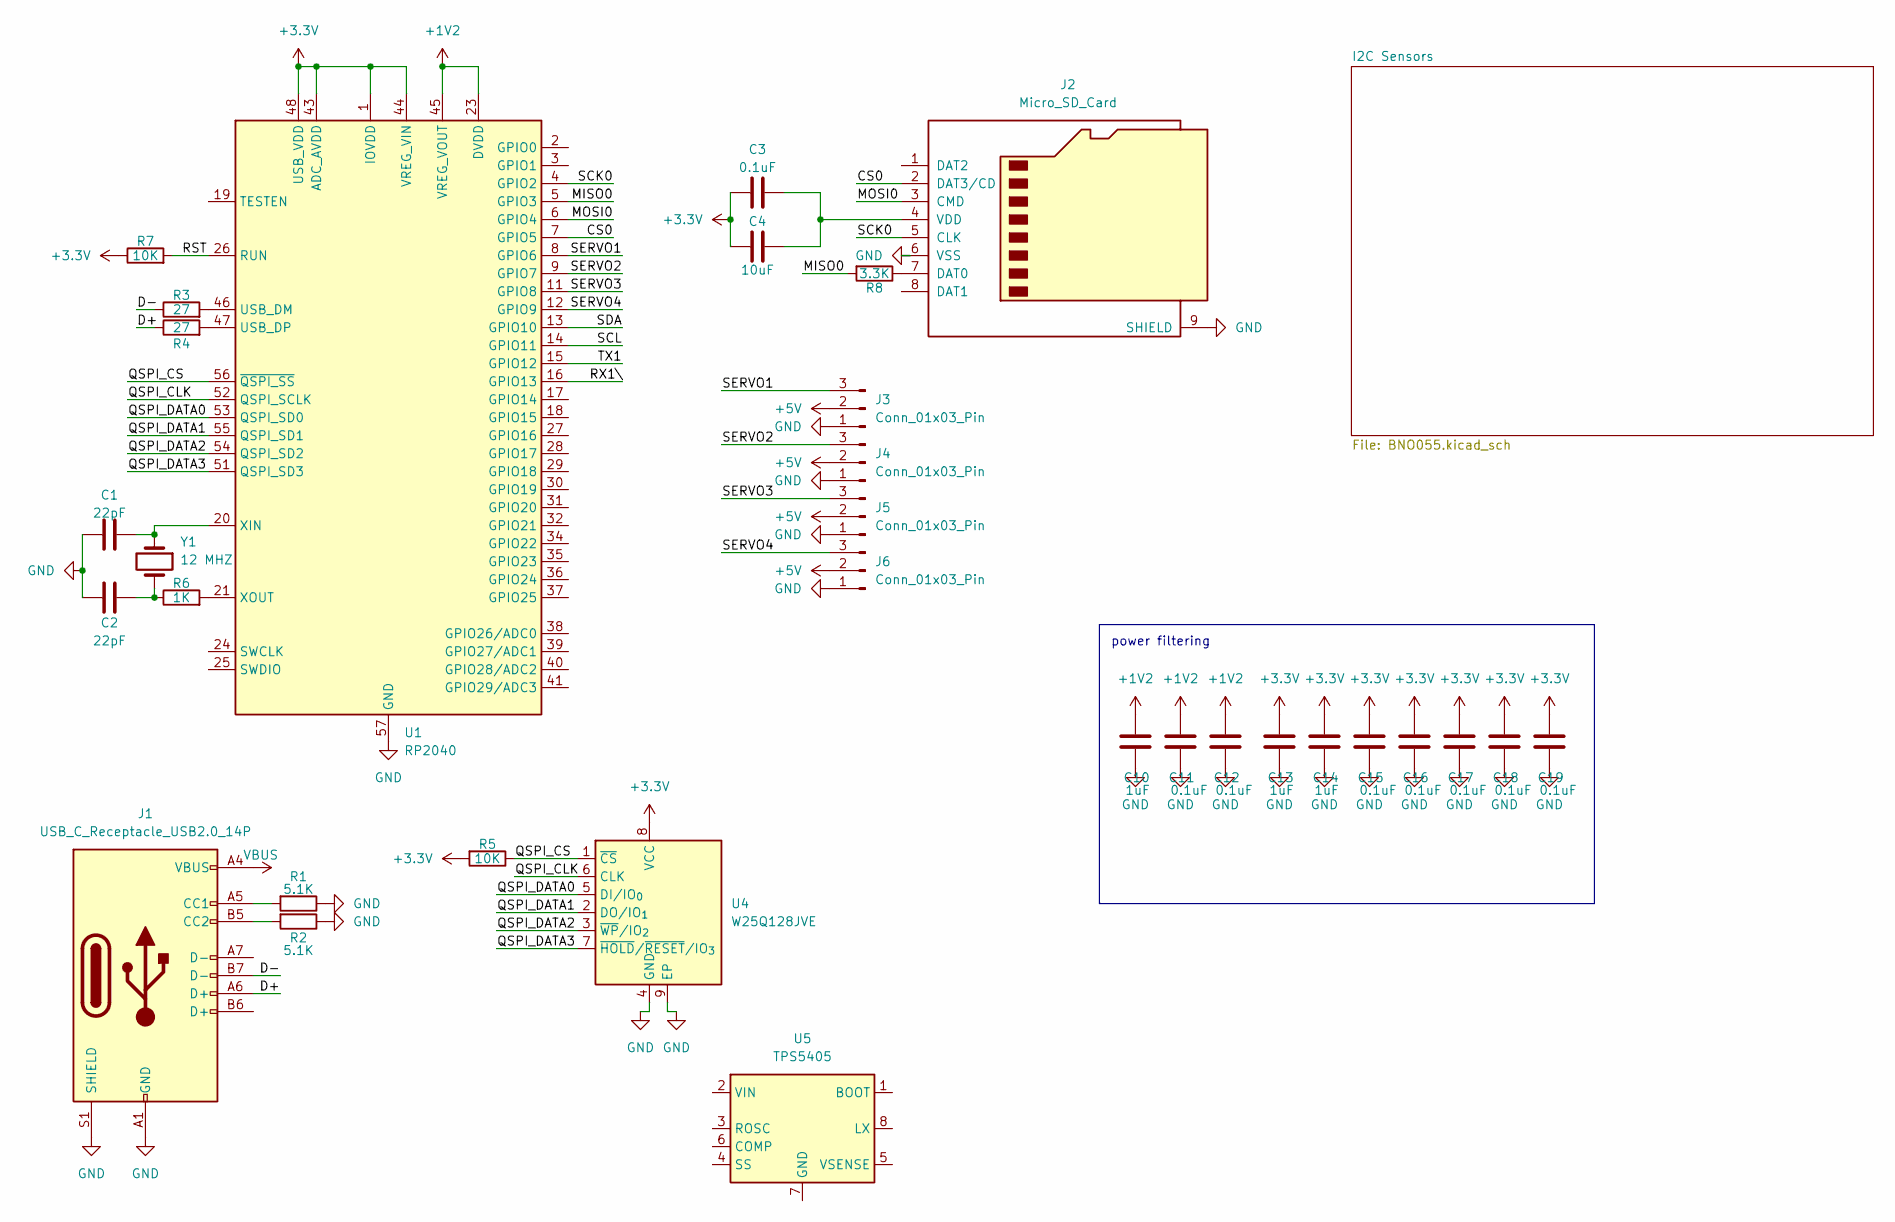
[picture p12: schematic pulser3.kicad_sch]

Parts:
C1, C2: 22pF; C_0805_2012Metric
C3, C11, C12, C15, C16, C17, C18, C19: 0.1uF; C_0805_2012Metric
C4: 10uF; C_0805_2012Metric
C10, C13, C14: 1uF; C_0805_2012Metric
J1: USB_C_Receptacle_USB2.0_14P; USB_C_Receptacle_GCT_USB4105-xx-A_16P_TopMnt_Horizontal
J2: Micro_SD_Card; microSD_HC_Hirose_DM3D-SF
J3, J4, J5, J6: Conn_01x03_Pin; PinHeader_1x03_P2.54mm_Vertical
R1, R2: 5.1K; R_0603_1608Metric
R3, R4: 27; R_0603_1608Metric
R5, R7: 10K; R_0603_1608Metric
R6: 1K; R_0603_1608Metric
R8: 3.3K; R_0603_1608Metric
U1: RP2040; QFN-56-1EP_7x7mm_P0.4mm_EP3.2x3.2mm
U4: W25Q128JVE; WSON-8-1EP_8x6mm_P1.27mm_EP3.4x4.3mm
U5: TPS5405; SOIC-8_3.9x4.9mm_P1.27mm
Y1: 12 MHZ; Crystal_SMD_3215-2Pin_3.2x1.5mm

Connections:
+1V2: C10.1, C11.1, C12.1, U1.23 (DVDD), U1.45 (VREG_VOUT), U1.50 (DVDD)
+5V: J3.2, J4.2, J5.2, J6.2
/CS0: J2.2 (DAT3/CD), U1.7 (GPIO5)
/D+: J1.A6 (D+), R4.1
/D-: J1.B7 (D-), R3.1
/MISO0: R8.2, U1.5 (GPIO3)
/MOSI0: J2.3 (CMD), U1.6 (GPIO4)
/QSPI_CLK: U1.52 (QSPI_SCLK), U4.6 (CLK)
/QSPI_CS: R5.1, U1.56 (~QSPI_SS), U4.1 (~CS)
/QSPI_DATA0: U1.53 (QSPI_SD0), U4.5 (DI/IO_{0})
/QSPI_DATA1: U1.55 (QSPI_SD1), U4.2 (DO/IO_{1})
/QSPI_DATA2: U1.54 (QSPI_SD2), U4.3 (~WP/IO_{2})
/QSPI_DATA3: U1.51 (QSPI_SD3), U4.7 (~HOLD/~RESET/IO_{3})
/RST: R7.2, U1.26 (RUN)
/RX1\: U1.16 (GPIO13)
/SCK0: J2.5 (CLK), U1.4 (GPIO2)
/SCL: U1.14 (GPIO11)
/SDA: U1.13 (GPIO10)
/SERVO1: J3.3, U1.8 (GPIO6)
/SERVO2: J4.3, U1.9 (GPIO7)
/SERVO3: J5.3, U1.11 (GPIO8)
/SERVO4: J6.3, U1.12 (GPIO9)
/TX1: U1.15 (GPIO12)
unnamed: C2.2, R6.1, Y1.2
unnamed: J1.A5 (CC1), R1.2
unnamed: J1.B5 (CC2), R2.2
unnamed: J2.7 (DAT0), R8.1
unnamed: C3.1, C4.1, J2.4 (VDD)
unnamed: R3.2, U1.46 (USB_DM)
unnamed: R4.2, U1.47 (USB_DP)
unnamed: C1.2, U1.20 (XIN), Y1.1
unnamed: R6.2, U1.21 (XOUT)
VBUS: J1.A4 (VBUS), J1.A9 (VBUS), J1.B4 (VBUS), J1.B9 (VBUS)

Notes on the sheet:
power filtering

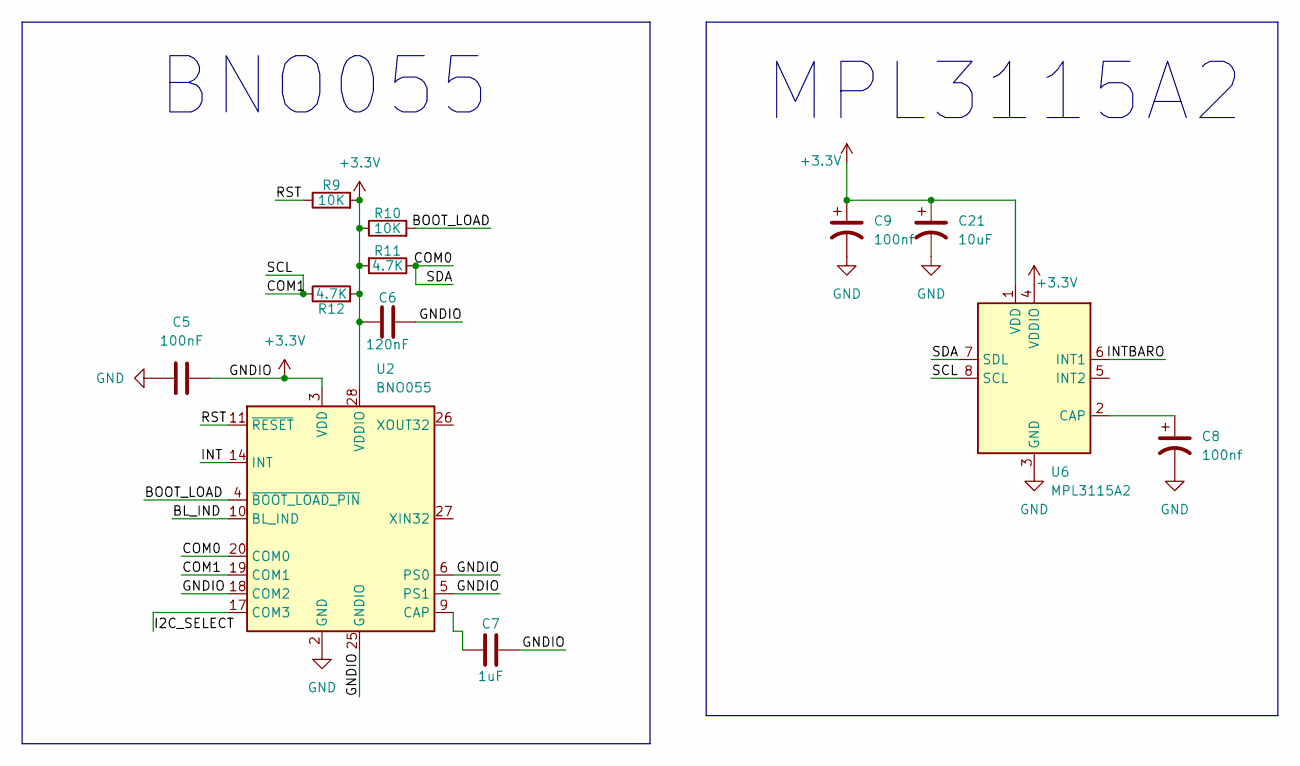
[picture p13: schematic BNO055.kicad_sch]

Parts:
C5: 100nF; C_0805_2012Metric
C6: 120nF; C_0805_2012Metric
C7: 1uF; C_0805_2012Metric
C8, C9: 100nf
C21: 10uF
R9, R10: 10K; R_0603_1608Metric
R11, R12: 4.7K; R_0603_1608Metric
U2: BNO055; LGA-28_5.2x3.8mm_P0.5mm
U6: MPL3115A2; NXP_LGA-8_3x5mm_P1.25mm_H1.1mm

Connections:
/I2C Sensors/BL_IND: U2.10 (BL_IND)
/I2C Sensors/BOOT_LOAD: R10.2, U2.4 (~BOOT_LOAD_PIN)
/I2C Sensors/COM0: R11.1, U2.20 (COM0), U6.7 (SDL); also elsewhere on the board
/I2C Sensors/COM1: R12.1, U2.19 (COM1), U6.8 (SCL); also elsewhere on the board
/I2C Sensors/I2C_SELECT: U2.17 (COM3)
/I2C Sensors/INT: U2.14 (INT)
/I2C Sensors/RST: R9.1, U2.11 (~RESET)
unnamed: C7.2, U2.9 (CAP)

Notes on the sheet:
BNO055
MPL3115A2

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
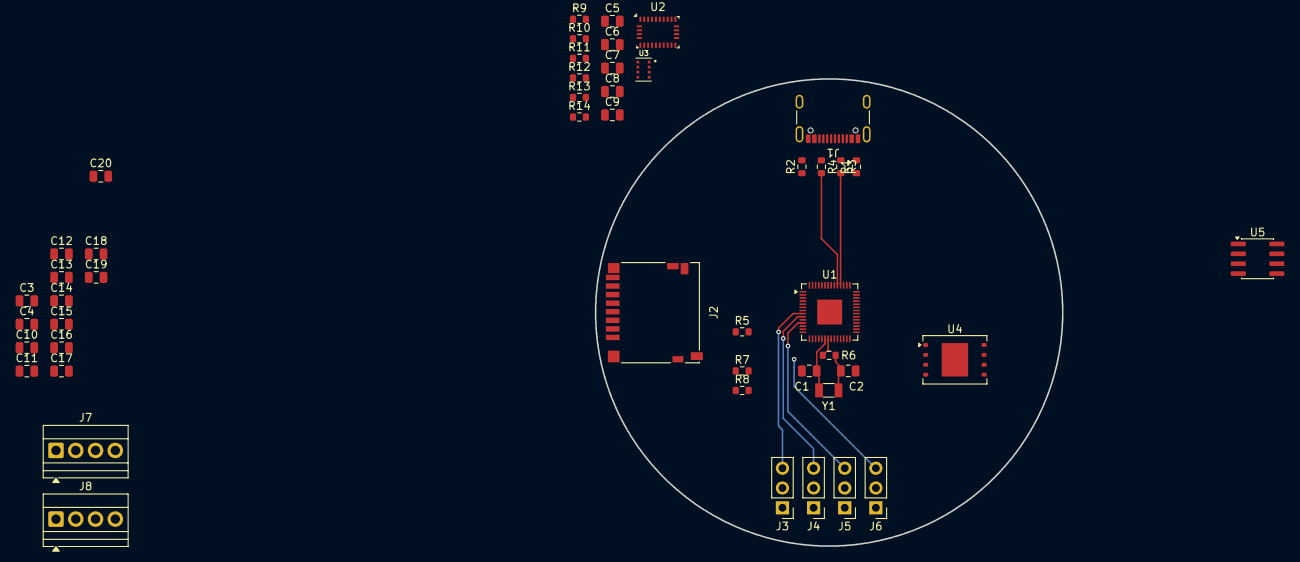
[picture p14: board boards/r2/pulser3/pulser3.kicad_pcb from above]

Board: 4 copper layers, 60.0 x 60.0 mm, 48 parts (0 on the bottom side), 37 nets.

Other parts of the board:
C20: C; C_0805_2012Metric
J7, J8: Screw_Terminal_01x04; TerminalBlock_Xinya_XY308-2.54-4P_1x04_P2.54mm_Horizontal
R13, R14: 4.7K; R_0603_1608Metric
U3: DPS310XTSA1; XDCR_DPS310XTSA1

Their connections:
/I2C Sensors/COM0: R14.2, U3.3 (SDI); also elsewhere on the board
/I2C Sensors/COM1: R13.2, U3.4 (SCK); also elsewhere on the board
/I2C Sensors/VDDIO: R13.1, R14.1

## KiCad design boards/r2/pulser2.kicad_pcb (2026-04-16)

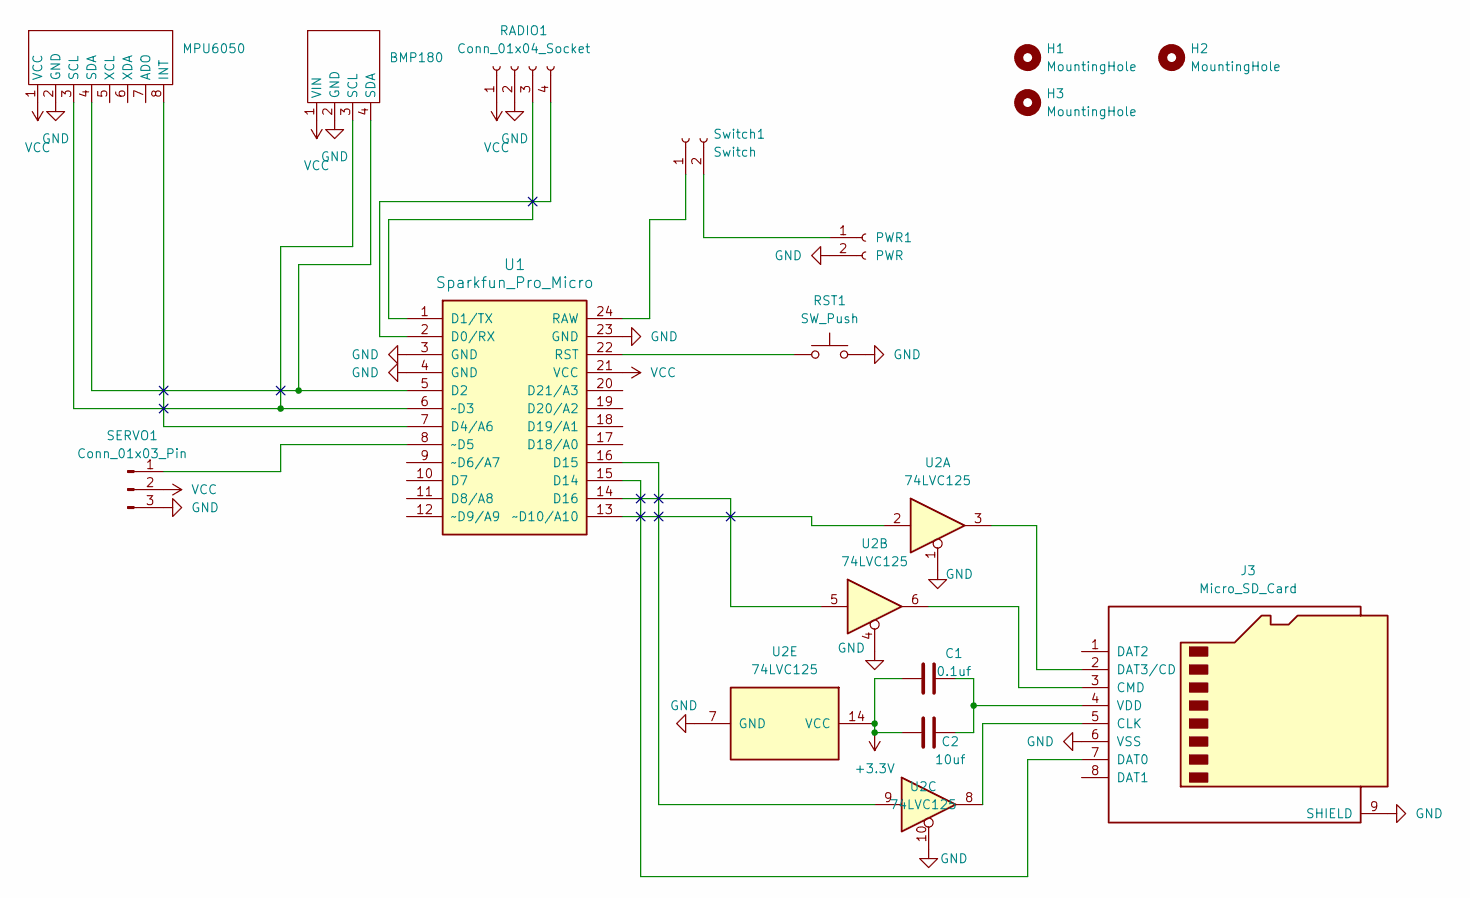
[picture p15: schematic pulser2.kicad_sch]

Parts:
BMP180: bmp180
C1: 0.1uf; C_0603_1608Metric_Pad1.08x0.95mm_HandSolder
C2: 10uf; C_0805_2012Metric_Pad1.18x1.45mm_HandSolder
H1, H2, H3: MountingHole; MountingHole_2.2mm_M2
J3: Micro_SD_Card; microSD_HC_Hirose_DM3D-SF
MPU6050: gy521
PWR1: PWR; JST_XH_B2B-XH-A_1x02_P2.50mm_Vertical
RADIO1: Conn_01x04_Socket; JST_XH_B4B-XH-A_1x04_P2.50mm_Vertical
RST1: SW_Push; SW_PUSH_6mm_H5mm
SERVO1: Conn_01x03_Pin; PinHeader_1x03_P2.54mm_Horizontal
Switch1: Switch; JST_XH_B2B-XH-A_1x02_P2.50mm_Vertical
U1: Sparkfun_Pro_Micro
U2: 74LVC125; SOIC-14_3.9x8.7mm_P1.27mm

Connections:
+3.3V: C1.2, C2.2, U2.14 (VCC)
GND: BMP180.2 (GND), J3.6 (VSS), J3.9 (SHIELD), MPU6050.2 (GND), PWR1.2, RADIO1.2, RST1.2, SERVO1.3, U1.3 (GND), U1.4 (GND), U1.23 (GND), U2.1, U2.4, U2.7 (GND), U2.10
unnamed: BMP180.3 (SCL), MPU6050.3 (SCL), U1.6 (~D3)
unnamed: BMP180.4 (SDA), MPU6050.4 (SDA), U1.5 (D2)
unnamed: J3.5 (CLK), U2.8
unnamed: J3.3 (CMD), U2.6
unnamed: J3.7 (DAT0), U1.15 (D14)
unnamed: J3.2 (DAT3/CD), U2.3
unnamed: C1.1, C2.1, J3.4 (VDD)
unnamed: MPU6050.8 (INT), U1.7 (D4/A6)
unnamed: PWR1.1, Switch1.2
unnamed: RADIO1.3, U1.1 (D1/TX)
unnamed: RADIO1.4, U1.2 (D0/RX)
unnamed: SERVO1.1, U1.8 (~D5)
unnamed: Switch1.1, U1.24 (RAW)
unnamed: U1.16 (D15), U2.9
unnamed: U1.14 (D16), U2.5
unnamed: RST1.1, U1.22 (RST)
unnamed: U1.13 (~D10/A10), U2.2
VCC: BMP180.1 (VIN), MPU6050.1 (VCC), RADIO1.1, SERVO1.2, U1.21 (VCC)

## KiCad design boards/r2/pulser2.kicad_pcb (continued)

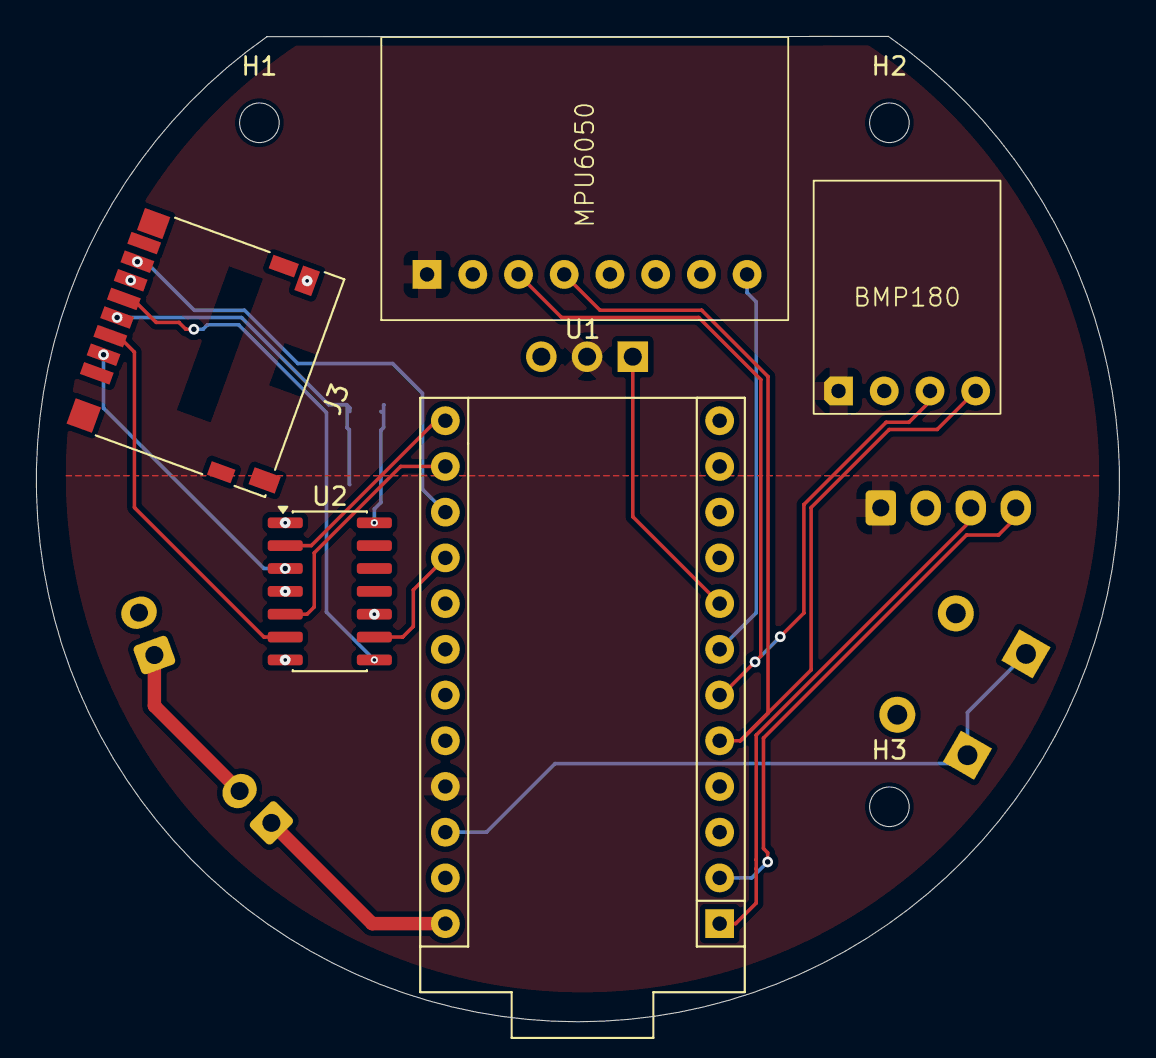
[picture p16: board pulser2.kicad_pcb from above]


Board: 2 copper layers, 60.2 x 54.7 mm, 15 parts (7 on the bottom side), 20 nets.

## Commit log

2026-04-16 Initial Pulse repo with r2 and r2.1 revisions
    [BNO055.kicad_sch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]
2026-04-16 added pulser3 - revised layout of pulse r2.1
    [pulser3.kicad_pcb, pulser3.kicad_sch]
2026-05-21 Update pulser3 board files
    [RPH0016A.stp, pulser3.kicad_pcb, pulser3.kicad_sch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]
